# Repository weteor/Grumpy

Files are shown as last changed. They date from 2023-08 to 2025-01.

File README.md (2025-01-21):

### grumpy

28 key (3-row) angled unibody keyboard with col stagger 

top

## Features

###### MX Xiao-Version:

- spacing: MX
- case: open bottom (3dp)
- Hotswap sockets (MX)
- Seeed Xiao Controller
  - RP2040 (w/ QMK, Vial)
  - BLE (w/ZMK)
  - SAMD21 (should work, don't have one to test)
- gerber and case files are supplied (kicad files, stl as well as cadquery files)
- completely open source, permissive license ([CERN-OHL-P](https://cern-ohl.web.cern.ch/home))

###### MX/ChocV2 CH552T-Version:

- spacing: MX
- case: top w/ bottom plate (top and bottom 3dp)
- Hotswap sockets (MX and Choc V1/V2)
- CH552T Controller (w/ FAK firmware)
- gerber and case files are supplied (kicad files, stl as well as cadquery files)
- completely open source, permissive license ([CERN-OHL-P](https://cern-ohl.web.cern.ch/home))

###### ChocV1 Xiao-Version:

- spacing: choc
- case: top w/ bottom plate (top 3dp/cnc, bottom 3dp)
- Hotswap sockets (Choc V1)
- Seeed Xiao Controller
  - RP2040 (w/ QMK, Vial)
  - BLE (w/ZMK)
  - SAMD21 (should work, don't have one to test)
- gerber and case files are supplied (kicad files, stl as well as cadquery files)
- completely open source, permissive license ([CERN-OHL-P](https://cern-ohl.web.cern.ch/home))

## Want one?

All production files you need to build your own board can be found [here](./prod/).

The case has no bottom and ends right below the HS Sockets. You may either use it as is, but preferably use some 2-3mm self-adhesive neopren on the whole pcb. The case will be hard to print on a FDM Printer, so maybe use a service to print it in resin or nylon.

Apart from the pcb and optionally a case you need:

###### Xiao-Version

- 28 hotswap sockets
- 28 diodes (1N4148 int SOT-123)
- 28 of your favourite switches
- 1 Controller

###### CH552T-Version:

- 28 hotswap sockets
- 28 diodes (1N4148 int SOT-123)
- 28 of your favourite switches
- 1x CH552T (TSSOP-20)
- 1x USBLC6-2SC6 (SOT-23-6)
- 1x 10kOhm resistor (SMD 0603)
- 2x 5.1kOhm resistors (SMD 0603)
- 2x 100nF capacitors (SMD 0603)
- 1x USB Connector C-Type, 12 pin/16pin, mid-mount (1.6mm)

### firmware

###### Xiao-Version:

firmware configs for qmk and vial can be found in the [firmware folder](./firmware).

The first time the pcb is plugged in, the bootloader will provide a drive to upload the firmware file. 

###### CH552T-Version:

firmware config for FAK can be found [here](https://github.com/weteor/fak-config/tree/main/keyboards/grumpy). Please also see [FAK-Firmware site](https://github.com/semickolon/fak) for more information

Bootloader should be available on first plugins until firmware is written. After that either use the firmware BOOT to go into bootloader, or hold the boot button on the pcb pressed while pluggin in the usb cable.

## the rest

Everything in this repository is free to use however you might see fit. If you want to support me and my projects, please consider linking back to this repository if you build/change/use anything.

If you would like to send me a tip, you could do it [here](https://ko-fi.com/weteor) (Please don't feel like you have to).

## more pictures

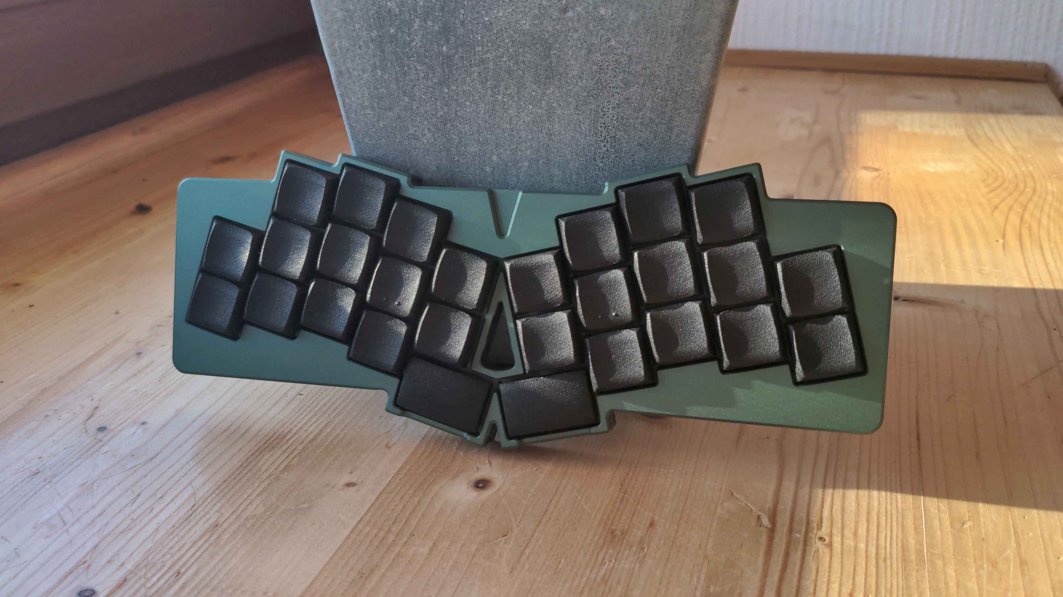
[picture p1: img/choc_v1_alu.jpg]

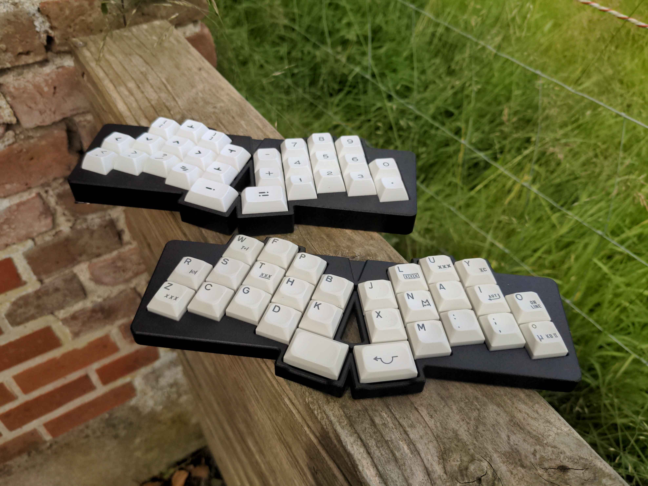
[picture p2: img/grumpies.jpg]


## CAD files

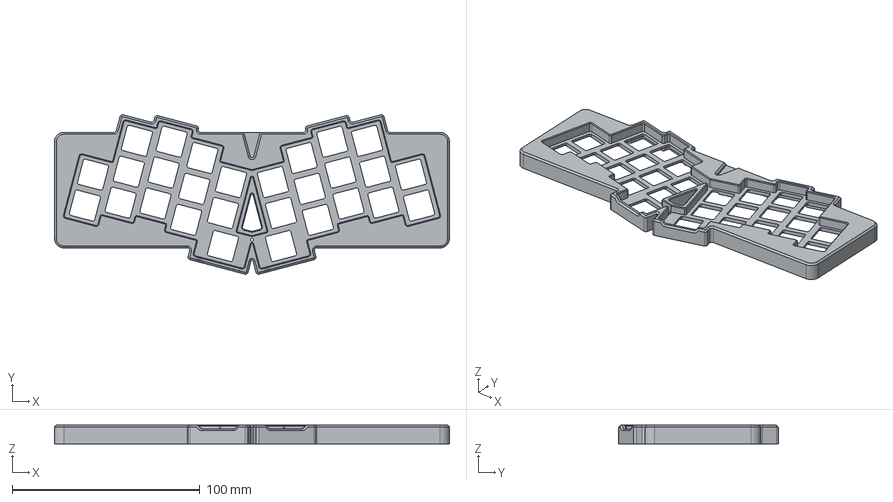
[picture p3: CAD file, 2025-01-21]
prod/ChocV1 low profile/case_choc/grumpy_lp_choc_top.step
210.2 x 84.9 x 10.0 mm

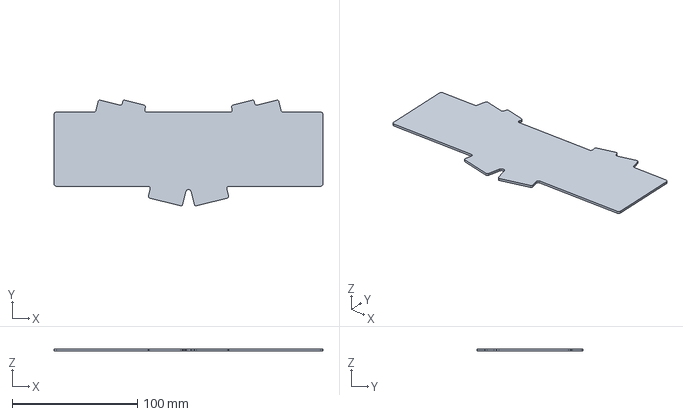
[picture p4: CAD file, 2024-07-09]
prod/MX ChocV2 low profile/case_chocV2/grumpy_lp_bottom.step
214.7 x 84.4 x 1.70 mm

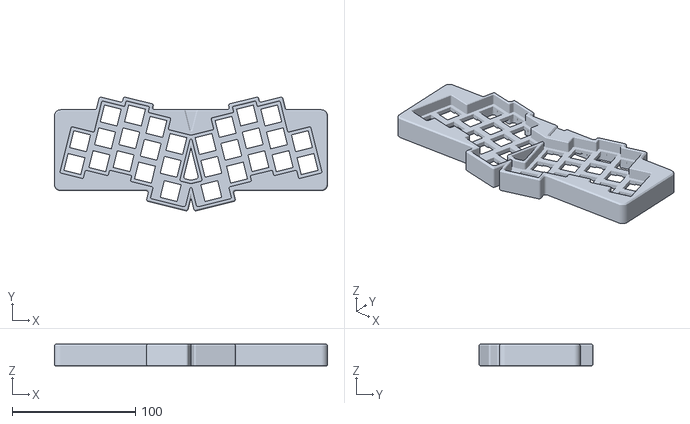
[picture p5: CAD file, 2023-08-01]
prod/MX Xiao/case_mx/grumpy.stl
221.1 x 92.1 x 17.7

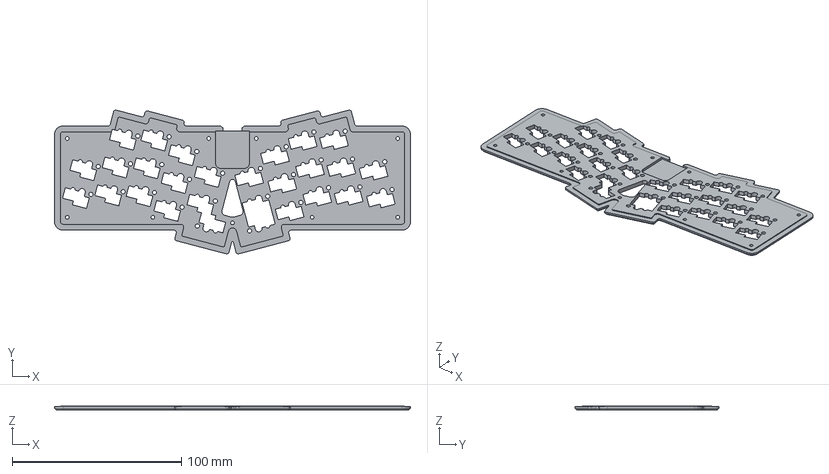
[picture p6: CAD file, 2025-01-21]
prod/ChocV1 low profile/case_choc/grumpy_lp_choc_bottom.step
210.1 x 84.9 x 2.50 mm

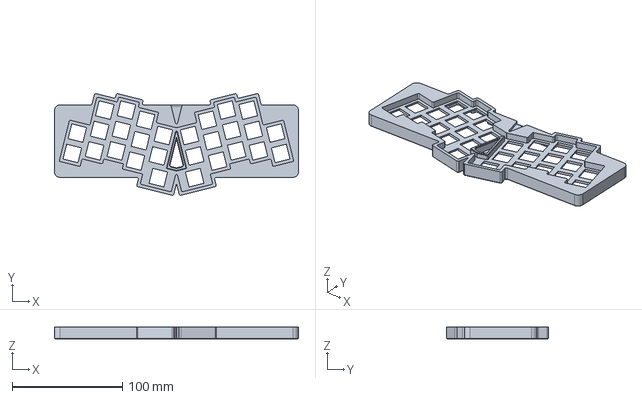
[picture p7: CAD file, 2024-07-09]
prod/MX ChocV2 low profile/case_chocV2/grumpy_lp.step
221.1 x 92.1 x 11.1 mm

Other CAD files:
prod/MX ChocV2 low profile/case_chocV2/grumpy_lp.stl
prod/MX ChocV2 low profile/case_chocV2/grumpy_lp_bottom.stl

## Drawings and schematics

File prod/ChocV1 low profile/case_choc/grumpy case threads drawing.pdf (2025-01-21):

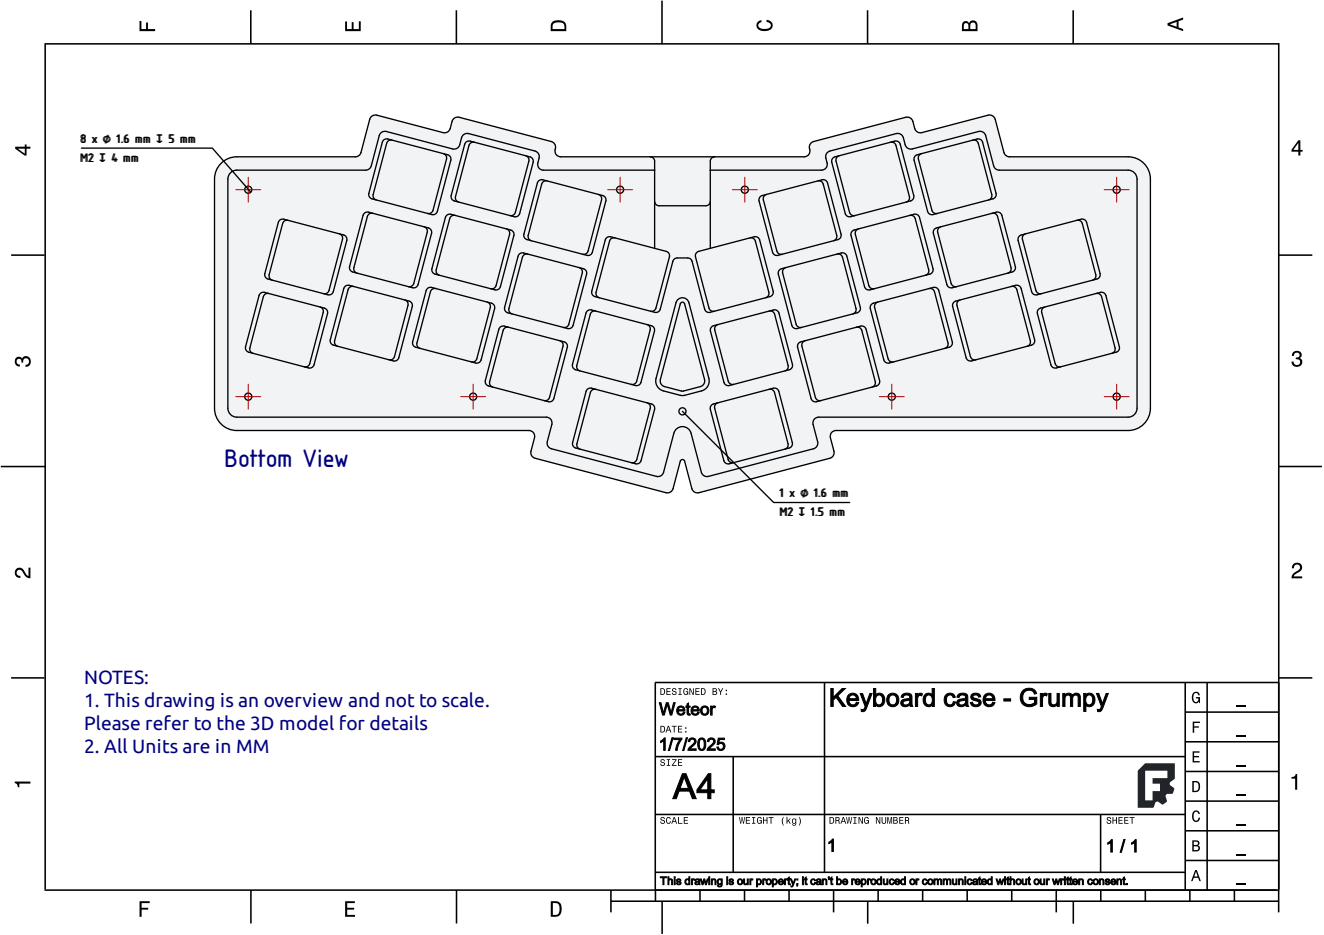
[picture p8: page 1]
Bottom View

88 xx ⌀⌀ 11..66 mmmm ↧↧ 55 mmmm MM22 ↧↧ 44 mmmm

11 xx ⌀⌀ 11..66 mmmm MM22 ↧↧ 11..55 mmmm

NOTES:
1. This drawing is an overview and not to scale. Please refer to the 3D model for details

2. All Units are in MM

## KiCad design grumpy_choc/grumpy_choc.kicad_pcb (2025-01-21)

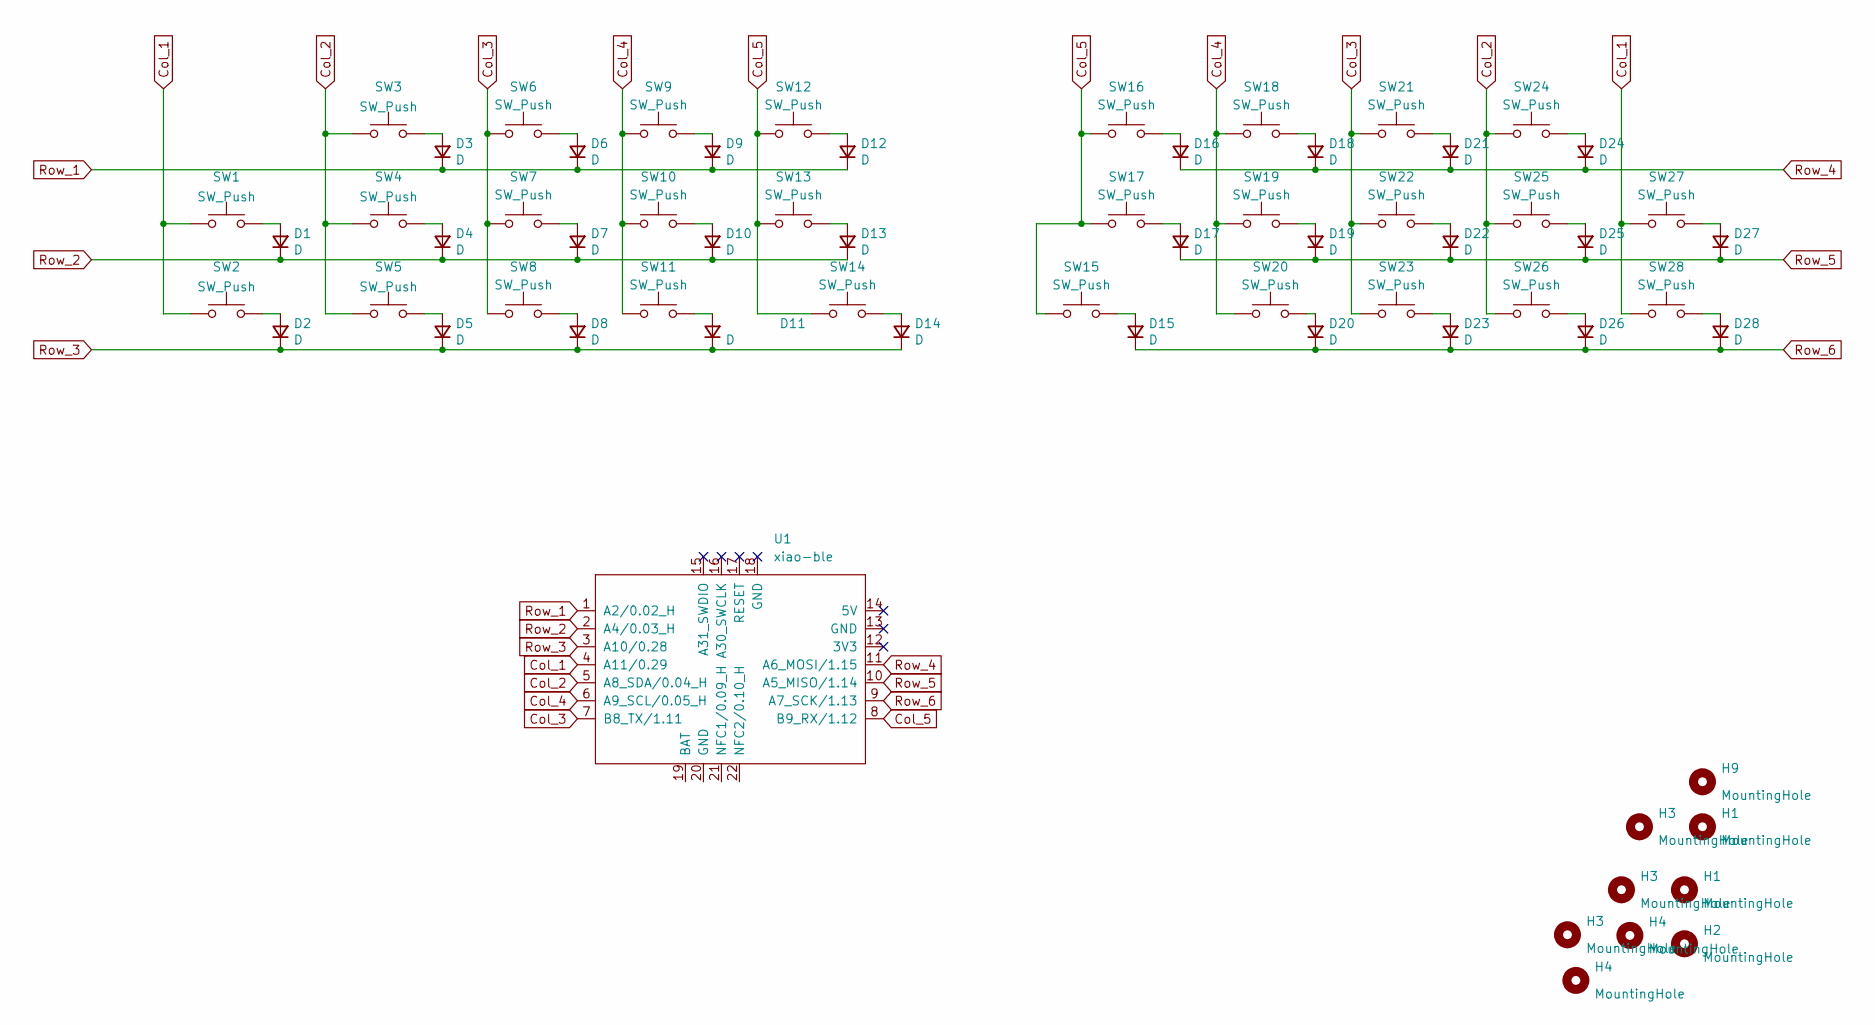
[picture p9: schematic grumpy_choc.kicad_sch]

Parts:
D1, D2, D3, D4, D5, D6, D7, D8, D9, D10, D11, D12, D13, D14, D15, D16, D17, D18, D19, D20, D21, D22, D23, D24, D25, D26, D27, D28: D; D_SOD-123
H1, H2, H3, H4, H9: MountingHole; MountingHole_4mm
SW1, SW2, SW3, SW4, SW5, SW6, SW7, SW8, SW9, SW10, SW11, SW12, SW13, SW16, SW17, SW18, SW19, SW20, SW21, SW22, SW23, SW24, SW25, SW26, SW27, SW28: SW_Push; ChocV1_V2_Hotswap
SW14, SW15: SW_Push; ChocV1_V2_Hotswap_1.5u
U1: xiao-ble; xiao-ble-smd_upside_down_npads

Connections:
Col_1: SW1.1, SW2.1, SW27.1, SW28.1, U1.4 (A11/0.29)
Col_2: SW3.1, SW4.1, SW5.1, SW24.1, SW25.1, SW26.1, U1.5 (A8_SDA/0.04_H)
Col_3: SW6.1, SW7.1, SW8.1, SW21.1, SW22.1, SW23.1, U1.7 (B8_TX/1.11)
Col_4: SW9.1, SW10.1, SW11.1, SW18.1, SW19.1, SW20.1, U1.6 (A9_SCL/0.05_H)
Col_5: SW12.1, SW13.1, SW14.1, SW15.1, SW16.1, SW17.1, U1.8 (B9_RX/1.12)
unnamed: D1.2 (A), SW1.2
unnamed: D2.2 (A), SW2.2
unnamed: D3.2 (A), SW3.2
unnamed: D4.2 (A), SW4.2
unnamed: D5.2 (A), SW5.2
unnamed: D6.2 (A), SW6.2
unnamed: D7.2 (A), SW7.2
unnamed: D8.2 (A), SW8.2
unnamed: D9.2 (A), SW9.2
unnamed: D10.2 (A), SW10.2
unnamed: D11.2 (A), SW11.2
unnamed: D12.2 (A), SW12.2
unnamed: D13.2 (A), SW13.2
unnamed: D14.2 (A), SW14.2
unnamed: D15.2 (A), SW15.2
unnamed: D16.2 (A), SW16.2
unnamed: D17.2 (A), SW17.2
unnamed: D18.2 (A), SW18.2
unnamed: D19.2 (A), SW19.2
unnamed: D20.2 (A), SW20.2
unnamed: D21.2 (A), SW21.2
unnamed: D22.2 (A), SW22.2
unnamed: D23.2 (A), SW23.2
unnamed: D24.2 (A), SW24.2
unnamed: D25.2 (A), SW25.2
unnamed: D26.2 (A), SW26.2
unnamed: D27.2 (A), SW27.2
unnamed: D28.2 (A), SW28.2
Row_1: D3.1 (K), D6.1 (K), D9.1 (K), D12.1 (K), U1.1 (A2/0.02_H)
Row_2: D1.1 (K), D4.1 (K), D7.1 (K), D10.1 (K), D13.1 (K), U1.2 (A4/0.03_H)
Row_3: D2.1 (K), D5.1 (K), D8.1 (K), D11.1 (K), D14.1 (K), U1.3 (A10/0.28)
Row_4: D16.1 (K), D18.1 (K), D21.1 (K), D24.1 (K), U1.11 (A6_MOSI/1.15)
Row_5: D17.1 (K), D19.1 (K), D22.1 (K), D25.1 (K), D27.1 (K), U1.10 (A5_MISO/1.14)
Row_6: D15.1 (K), D20.1 (K), D23.1 (K), D26.1 (K), D28.1 (K), U1.9 (A7_SCK/1.13)

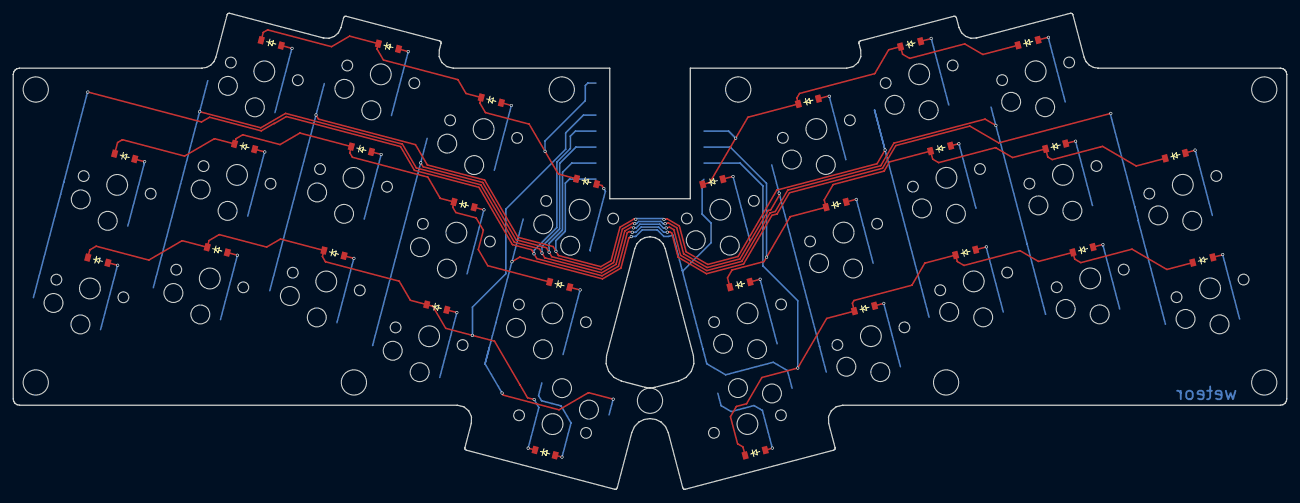
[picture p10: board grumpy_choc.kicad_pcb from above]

Board: 2 copper layers, 202.2 x 75.6 mm, 66 parts (1 on the bottom side), 39 nets.

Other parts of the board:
H5, H6, H7, H8: MountingHole; MountingHole_4mm

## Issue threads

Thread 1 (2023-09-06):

Clearance with SAMD21 hand-wired

PeterDigger, 2023-09-06:
Hi @weteor, I just wanted to say thank you for creating such a beautiful keyboard! I love the design ❤️.
This is not an issue with the keyboard, but I wanted to ask whether this can be hand-wired with SAMD21. What's the clearance with SAMD21? The reason I prefer hand-wiring over PCB is that none of my friends are interested in this type of keyboard (they prefer a "normal" keyboard), so there's no point in ordering PCBs when the minimum order quantity is 5 pieces.

Thank you!

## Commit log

2023-08-01 pcb cad data
    [grumpy.kicad_pcb, grumpy.kicad_sch]
2023-08-01 case cad files
2023-08-01 add production data
    [grumpy.stl]
2023-08-02 clean up case file
2024-07-09 add version with ch552t MCU and combined Choc V1, V2 and MX Footprints
    [grumpy.kicad_pcb, grumpy.kicad_sch, grumpy_ch522t.kicad_pcb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]
2024-07-09 add case for choc builds
    [grumpy.stl, grumpy_lp.step, grumpy_lp.stl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]
2024-07-09 add gerbers
2025-01-21 add choc-spaced Version
    [grumpy.stl, grumpy_choc.kicad_pcb, grumpy_choc.kicad_sch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]
